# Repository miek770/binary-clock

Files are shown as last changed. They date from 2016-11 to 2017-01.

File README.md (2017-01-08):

# Binary Clock

This is a simple binary clock project using a PIC18F2220, pretty much for:

1. The fun of it;
2. Getting more experience with Eagle PCB design;
3. Doing a first PIC C project (I've only programmed PICs in assembly before).

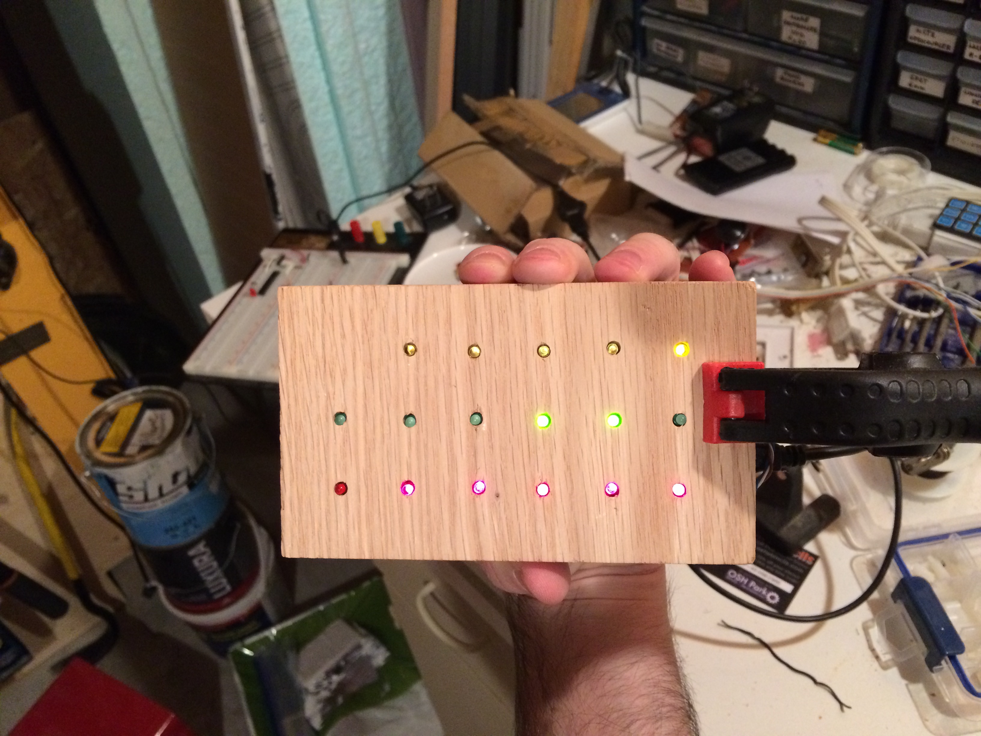
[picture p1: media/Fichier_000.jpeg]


The clamp on the right is there to hold down the buttons (hidden) while the glue dries up. More pictures in [media](https://github.com/miek770/binary-clock/tree/master/media)!

## To Do List

- Adjust timing to account for the cycles it takes for the time update and LED syncing. I noted an about 10 minutes drift over 24 hours, but I didn't take precise measurements at the beginning of the cycle. I just took another picture with my PC clock showing the seconds and the binary clock, and will compare the difference in at least 24 hours. I could also double-check by calculating the amount of cycles required for the interrupt subroutine;
    - Edit: This explaination is wrong; the timer doesn't stop counting while the ISR executes. I think the problem may be that I skip a "beat" because the ISR sometimes lasts longer than TMR0's 256 cycles counter. I'll see if the drift matches this assumption after a day.
- Test the low charge detection;
- Consider using delays.h instead of timer1 for the low-battery blink. The use of the timer seems unecessary and it would be a good excuse to explore the available functions;
- Consider importing timers.h to setup timer0, instead of manually setting each register;
- Consider using the idle power management mode when nothing is happening to reduce battery consumption. First check if it would interfere with timer0;

## Appearance

### Display

The clock uses 5 LEDs (bits) for the hours (24h format), 6 for the minutes and 6 for the seconds. Showing fractions of seconds seemed excessive.

## Supply

It can be fed either or by both:

1. 3x AA batteries;
2. A micro-USB port.

### Low Charge Detection

Both supplies are paralleled with diodes, and the PIC monitors the batteries' voltage so that an alarm (blinking LED) is raised when the batteries are low. For 1.5V AA batteries, this would be pretty much when they get under 1V. AN0 is used on the PIC to measure the battery voltage.

Hum thinking about it makes me realize that the voltage reference is Vdd. So if we ignore the voltage drop through the diode, which is gonna be constant, the voltage drop at the battery (with no USB supply) is going to drop proportionally with Vdd which means the AN0 measurement won't pick it up. Unless I use the voltage drop across the diode as a reference. At 4.5V at the batteries, with a 0.7V drop through the diode I'll get 3.8V at Vdd. When the batteries get to 3V (1V per cell), Vdd will equal 2.3V.

So Vbatt/Vdd = 4.5V/3.8V (1.184) at full charge, and 3V/2.3V (1.304) at low charge. Using a 50/50 voltage divider between Vbatt and AN0, the ratios would be 0.592 (full) and 0.652 (low). With a 10-bit A/D converter I have a 1024 resolution, which would be able to measure this. Basically the reading is going to go from 0/1023 to 1023/1023. A 0.592 ratio (full) would be read as 606 and a 0.652 ratio (low) as 667. So I could then consider any reading over 666 (0b1010011010) as a low battery charge.

This will need to be adjusted to account for the real diode voltage drop as well as the voltage divider ratio, but it should do the trick. For testing purposes I could use the time diodes to show the A/D conversion output. I have up to 17 bits (5+6+6 diodes).

## Timing

I switched from the PIC18F252 to the PIC18F2220 because the former doesn't have an internal oscillator. I assumed it did.

I will be using TMR0 to count seconds, using a bresenham algorithm as explained and implemented here: [http://www.romanblack.com/one_sec.htm](http://www.romanblack.com/one_sec.htm)

Basically (this is all from his website above):

    This next one is similar to the 1 second generators above. However it is optimised for speed and code space, because it uses a 16bit unsigned int variable for bres instead of a 32bit unsigned long. We do this by using values for the int period and the 1second period that are in the same ratio to each other, but smaller! We divide both values by 16;

    Optimised C code for a 1 second period with a 1MHz timer (4MHz xtal);

        // uses 1 variable; unsigned int bres
        // gets here every TMR0 int (every 256 ticks)

        bres += 16; // add (256/16) ticks to bresenham total

        if(bres >= 62500)   // if reached (1000000/16) 1 second!
        {
            bres -= 62500;  // subtract 1 second, retain error
            do_1sec_event();    // update clock, etc
        }

This is neat!

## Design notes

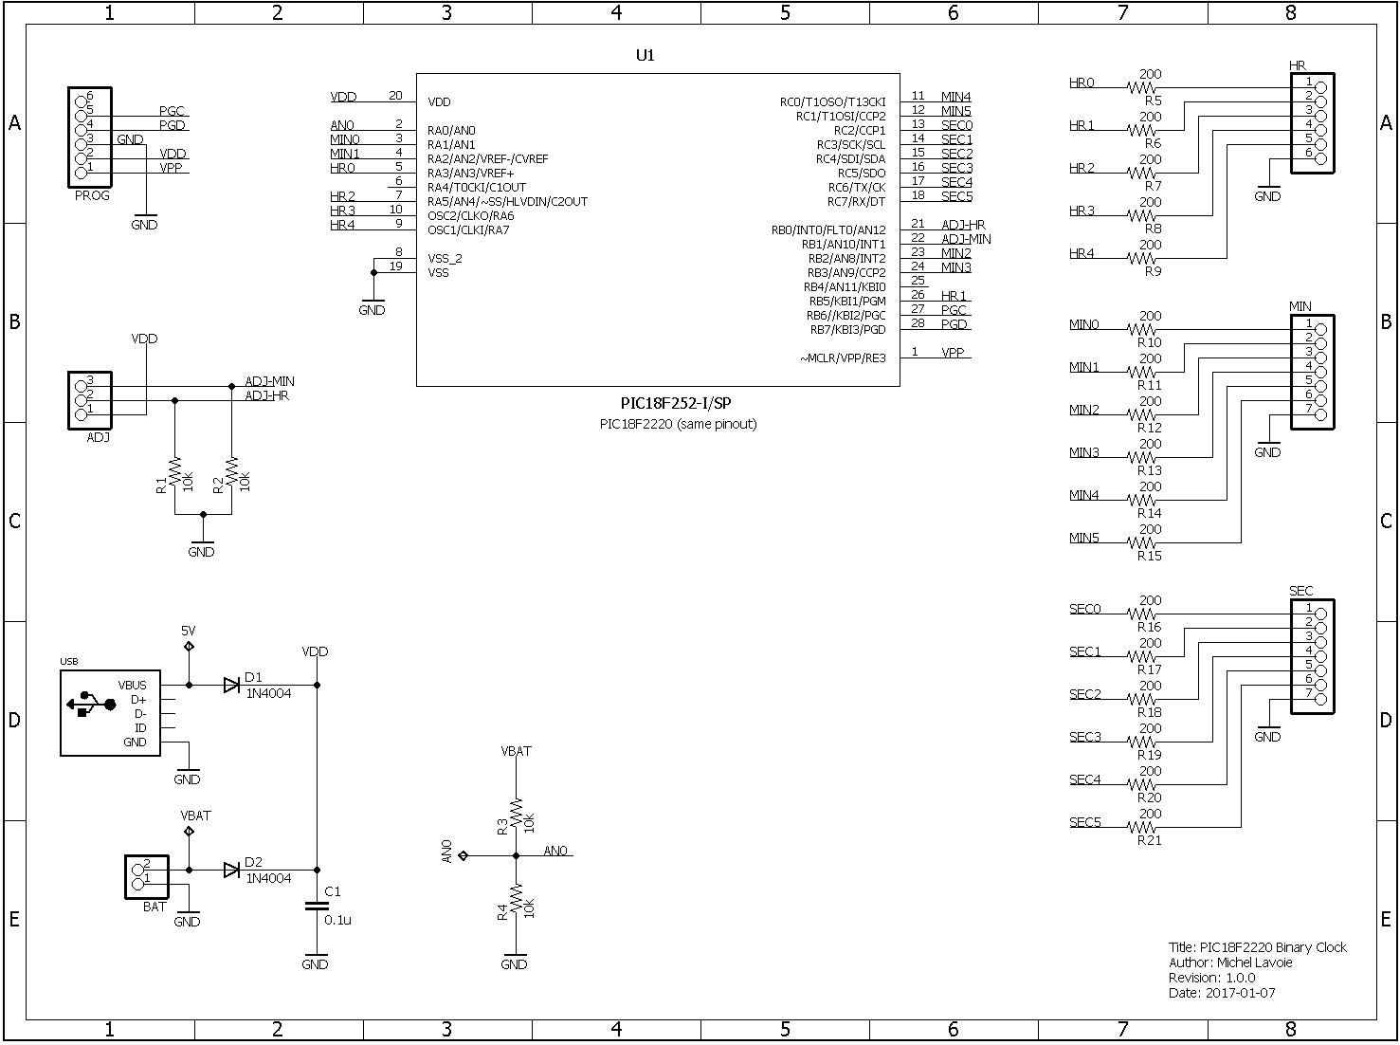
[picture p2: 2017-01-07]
media/Schematic.png

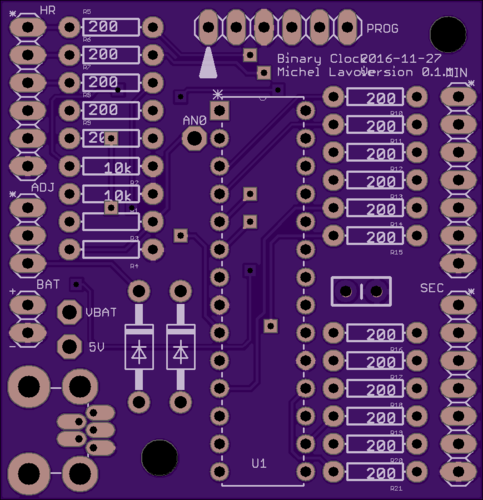
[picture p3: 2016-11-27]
media/Board Top.png

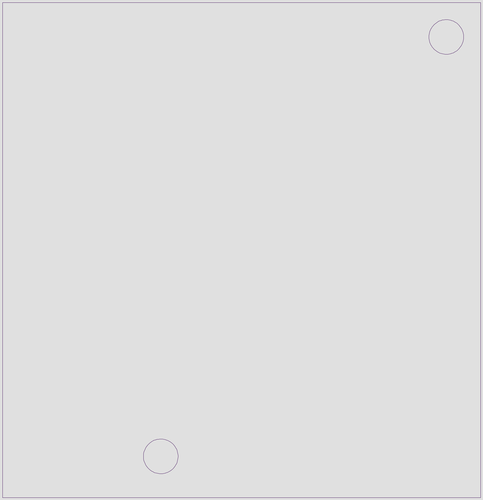
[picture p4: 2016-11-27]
media/Board Outline.png

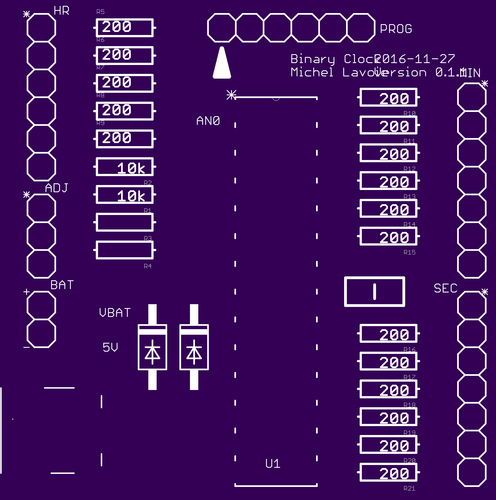
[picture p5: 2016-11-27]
media/Top Silk Screen.png

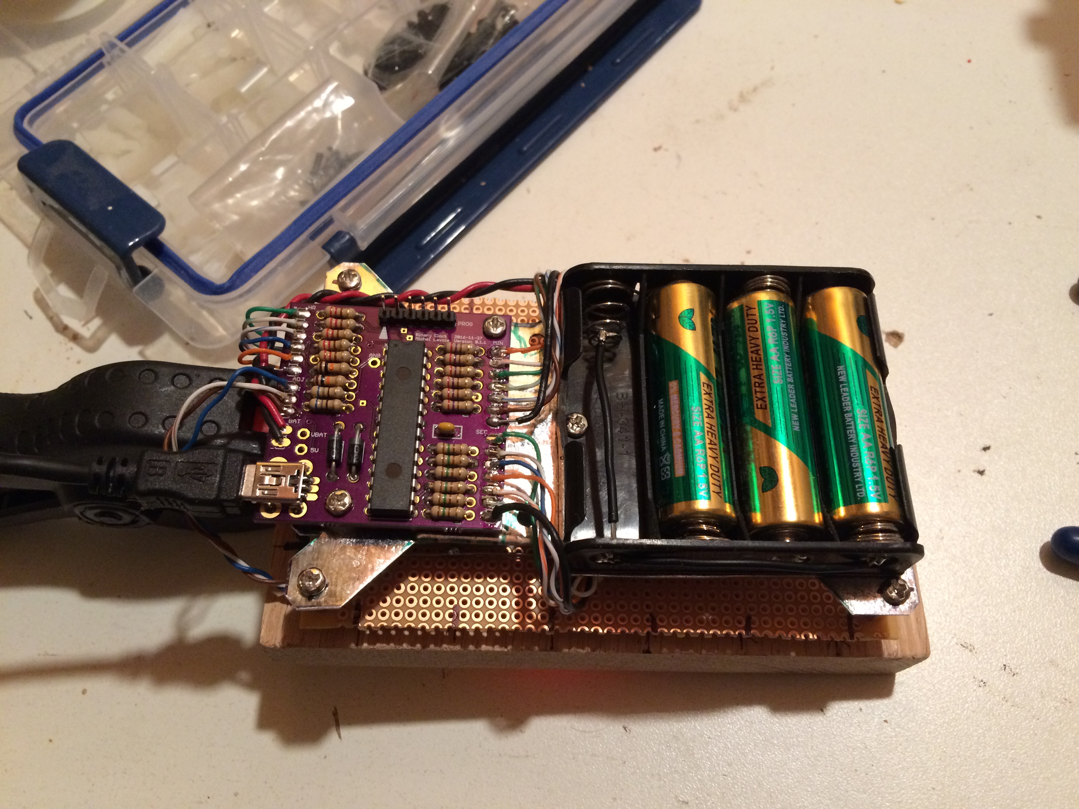
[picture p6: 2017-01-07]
media/Fichier_001.jpeg

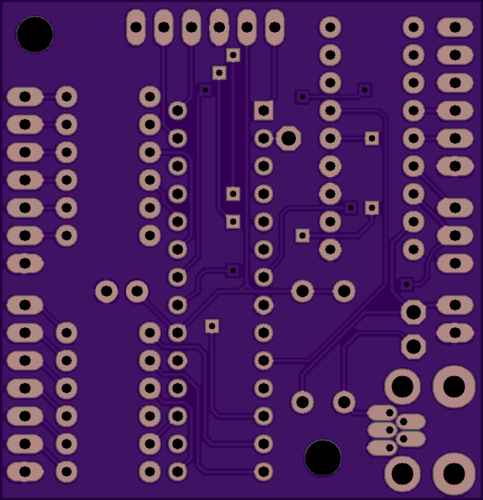
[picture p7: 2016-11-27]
media/Board Bottom.png

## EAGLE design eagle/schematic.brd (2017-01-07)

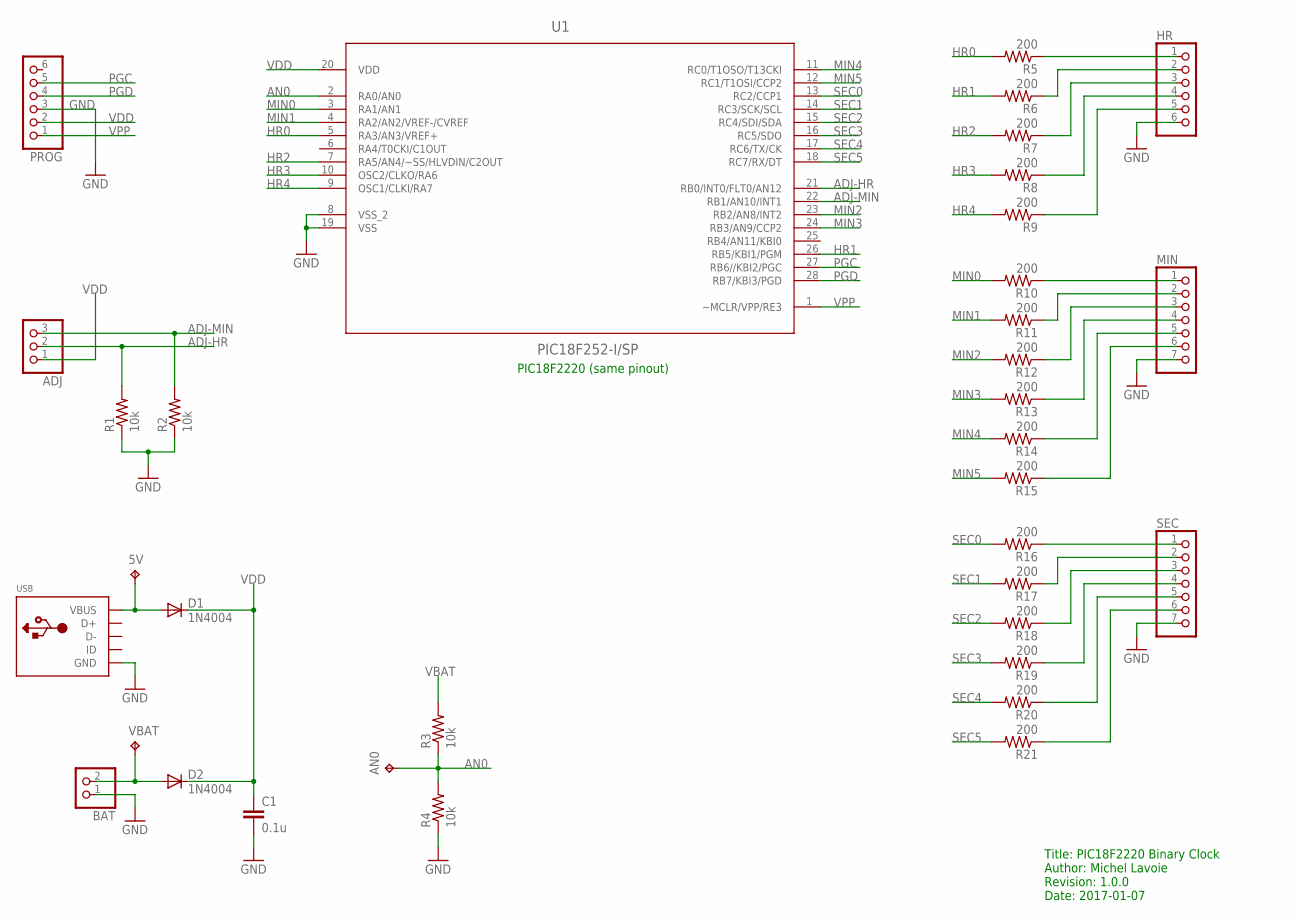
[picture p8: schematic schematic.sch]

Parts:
5V: TPPAD1-13; P1-13
ADJ: PINHD-1X3; 1X03
AN0: TPPAD1-13; P1-13
BAT: PINHD-1X2; 1X02
C1: 0.1u; CAP-PTH-SMALL-KIT
D1, D2: 1N4004; DO41-10
HR: PINHD-1X6; 1X06
MIN: PINHD-1X7; 1X07
PROG: PINHD-1X6; 1X06
R1, R2, R3, R4: 10k; AXIAL-0.3
R5, R6, R7, R8, R9, R10, R11, R12, R13, R14, R15, R16, R17, R18, R19, R20, R21: 200; AXIAL-0.3
SEC: PINHD-1X7; 1X07
U1: PIC18F252-I/SP; DIP254P762X508-28
USB: USBTHM; USB-MINIB-THM
VBAT: TPPAD1-13; P1-13

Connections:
5V: 5V.TP, D1.A, USB.VBUS
ADJ-HR: ADJ.2, R1.P$2 (2), U1.21 (RB0/INT0/FLT0/AN12)
ADJ-MIN: ADJ.3, R2.P$2 (2), U1.22 (RB1/AN10/INT1)
AN0: AN0.TP, R3.P$1 (1), R4.P$2 (2), U1.2 (RA0/AN0)
GND: BAT.1, C1.2, HR.6, MIN.7, PROG.3, R1.P$1 (1), R2.P$1 (1), R4.P$1 (1), SEC.7, U1.8 (VSS_2), U1.19 (VSS), USB.GND
HR0: R5.P$2 (2), U1.5 (RA3/AN3/VREF+)
HR1: R6.P$2 (2), U1.26 (RB5/KBI1/PGM)
HR2: R7.P$2 (2), U1.7 (RA5/AN4/~SS/HLVDIN/C2OUT)
HR3: R8.P$2 (2), U1.10 (OSC2/CLKO/RA6)
HR4: R9.P$2 (2), U1.9 (OSC1/CLKI/RA7)
MIN0: R10.P$2 (2), U1.3 (RA1/AN1)
MIN1: R11.P$2 (2), U1.4 (RA2/AN2/VREF-/CVREF)
MIN2: R12.P$2 (2), U1.23 (RB2/AN8/INT2)
MIN3: R13.P$2 (2), U1.24 (RB3/AN9/CCP2)
MIN4: R14.P$2 (2), U1.11 (RC0/T1OSO/T13CKI)
MIN5: R15.P$2 (2), U1.12 (RC1/T1OSI/CCP2)
unnamed: HR.1, R5.P$1 (1)
unnamed: HR.2, R6.P$1 (1)
unnamed: HR.3, R7.P$1 (1)
unnamed: HR.4, R8.P$1 (1)
unnamed: HR.5, R9.P$1 (1)
unnamed: MIN.1, R10.P$1 (1)
unnamed: MIN.2, R11.P$1 (1)
unnamed: MIN.3, R12.P$1 (1)
unnamed: MIN.4, R13.P$1 (1)
unnamed: MIN.5, R14.P$1 (1)
unnamed: MIN.6, R15.P$1 (1)
unnamed: R16.P$1 (1), SEC.1
unnamed: R17.P$1 (1), SEC.2
unnamed: R18.P$1 (1), SEC.3
unnamed: R19.P$1 (1), SEC.4
unnamed: R20.P$1 (1), SEC.5
unnamed: R21.P$1 (1), SEC.6
PGC: PROG.5, U1.27 (RB6//KBI2/PGC)
PGD: PROG.4, U1.28 (RB7/KBI3/PGD)
SEC0: R16.P$2 (2), U1.13 (RC2/CCP1)
SEC1: R17.P$2 (2), U1.14 (RC3/SCK/SCL)
SEC2: R18.P$2 (2), U1.15 (RC4/SDI/SDA)
SEC3: R19.P$2 (2), U1.16 (RC5/SDO)
SEC4: R20.P$2 (2), U1.17 (RC6/TX/CK)
SEC5: R21.P$2 (2), U1.18 (RC7/RX/DT)
VBAT: BAT.2, D2.A, R3.P$2 (2), VBAT.TP
VDD: ADJ.1, C1.1, D1.C, D2.C, PROG.2, U1.20 (VDD)
VPP: PROG.1, U1.1 (~MCLR/VPP/RE3)

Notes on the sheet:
Title: PIC18F2220 Binary Clock Author: Michel Lavoie Revision: 1.0.0 Date: 2017-01-07
PIC18F2220 (same pinout)

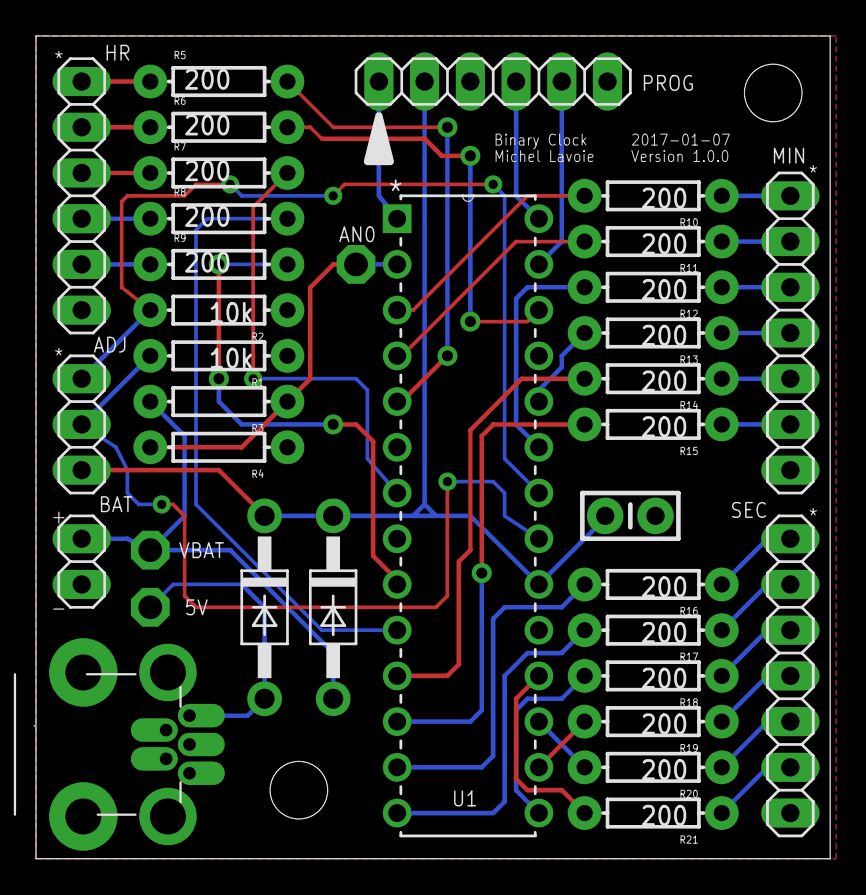
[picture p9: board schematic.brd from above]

Board: 2 copper layers, 44.1 x 45.7 mm, 35 parts (0 on the bottom side), 44 nets.

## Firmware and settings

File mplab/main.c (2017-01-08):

#include <p18f2220.h>

// Configuration
#pragma config OSC = INTIO2
#pragma config WDT = OFF
#pragma config BOR = OFF
#pragma config PWRT = OFF
#pragma config LVP = OFF
#pragma config MCLRE = OFF

// Prototypes - Functions
void update_time(void);
void refresh_clock(void);
void blink(void);
void sync_leds(void);
void isr(void);

// Prototypes - Configurations
void conf_tmr0(void);
void conf_adc(void);
void conf_int(void);
void conf_osc(void);
void conf_tmr1(void);
void conf_ports(void);
unsigned char get_bit(unsigned char byte, unsigned char pos);

/* Initialized variables declarations

Using "access" and "near" ensures that the data be saved in the accessram
region of the data memory (quicker access).

Using "volatile" is recommended by the C18 User's Guide when the variable
is to be used by the ISR as well as other functions. Basically it ensures
that the variable isn't cached during execution so changes in either the
normal program or interrupt routines are reflected in each other. */

#pragma idata access accessram
volatile near unsigned int bres = 0;
volatile near unsigned char hour = 0b11;
volatile near unsigned char min = 0b11;
volatile near unsigned char sec = 0b11;

// High-priority interrupt vector
#pragma code high_vector = 0x08
void interrupt_at_high_vector(void) {
	_asm GOTO isr _endasm
}

#pragma code

// Interrupt subroutine (priorities are disabled)

#pragma interrupt isr
void isr (void) {
	
	// See www.romanblack.com/one_sec.htm for details
	// Values below work for 4MHz clock (Fosc/4 = 1MHz)
	if (INTCONbits.TMR0IF) {
		bres += 16; // add (256/16) ticks to bresenham total
		//LATCbits.LATC7 ^= 1; // For testing

		if (bres >= 62500) { // if reached (1000000/16) 1 second!
			bres -= 62500; // subtract 1 second, retain error
			sec += 1;
			update_time();
			sync_leds();
			ADCON0bits.GO = 1; // Check battery level
		}

		INTCONbits.TMR0IF = 0; // Reset flag
	}

	// A/D conversion is complete
	else if (PIR1bits.ADIF) {
		// Check if battery voltage under 1V/cell
		if (ADRESH >= 0b10 && ADRESL >= 0b10011010) {
			blink(); // Initiates RA7 blink
		}
		PIR1bits.ADIF = 0; // Reset flag
	}

	// Time to blink!
	else if (PIR1bits.TMR1IF) {
		LATAbits.LATA7 ^= 1; // Toggle RA7
		T1CONbits.TMR1ON = 0; // Turn off TMR1
		PIR1bits.TMR1IF = 0; // Reset flag
	}

	// Hour adjustment!
	else if (INTCONbits.INT0IF) {
		hour += 1;
		update_time();
		sync_leds();
		INTCONbits.INT0IF = 0; // Reset flag
	}

	// Min adjustment!
	else if (INTCON3bits.INT1IF) {
		min += 1;
		update_time();
		sync_leds();
		INTCON3bits.INT1IF = 0; // Reset flag
	}
}

// Main code
#pragma code
void main (void) {
	conf_osc(); // Oscillator configuration
	conf_int(); // Interrupts configuration
	conf_tmr0(); // Timer0 - To count seconds
	conf_tmr1(); // Timer1 - To blink RA7 (low battery)
	conf_adc(); // A/D converter
	conf_ports(); // Ports A,B,C

	sync_leds();

	while (1); // Loop indefinitely
}

// Other functions
unsigned char get_bit(unsigned char byte, unsigned char pos) {
	return (byte >> pos) & 1;
}

void blink(void) {
	LATAbits.LATA7 ^= 1; // Toggle RA7
	T1CONbits.TMR1ON = 1; // Turn on TMR1
}

void update_time(void) {
	if (sec == 60) {
		sec = 0;
		min += 1;
		if (min == 60) {
			min = 0;
			hour += 1;
			if (hour == 24) {
				hour = 0;
			}
		}
	}
}

void sync_leds(void) {
	LATAbits.LATA3 = get_bit(hour, 0);
	LATBbits.LATB5 = get_bit(hour, 1);
	LATAbits.LATA5 = get_bit(hour, 2);
	LATAbits.LATA6 = get_bit(hour, 3);
	LATAbits.LATA7 = get_bit(hour, 4);

	LATAbits.LATA1 = get_bit(min, 0);
	LATAbits.LATA2 = get_bit(min, 1);
	LATBbits.LATB2 = get_bit(min, 2);
	LATBbits.LATB3 = get_bit(min, 3);
	LATCbits.LATC0 = get_bit(min, 4);
	LATCbits.LATC1 = get_bit(min, 5);

	LATCbits.LATC2 = get_bit(sec, 0);
	LATCbits.LATC3 = get_bit(sec, 1);
	LATCbits.LATC4 = get_bit(sec, 2);
	LATCbits.LATC5 = get_bit(sec, 3);
	LATCbits.LATC6 = get_bit(sec, 4);
	LATCbits.LATC7 = get_bit(sec, 5);
}

// Configurations
void conf_ports(void) {
	TRISA = 0b00010001;
	LATA = 0x00;
	TRISB = 0b11010011;
	LATB = 0x00;
	TRISC = 0b00000000;
	LATC = 0x00;
}

void conf_osc(void) {
	OSCCONbits.IDLEN = 1; // Idle mode enabled; CPU core is not clocked in power managed modes
	OSCCONbits.IRCF2 = 1; // 4 MHz
	OSCCONbits.IRCF1 = 1;
	OSCCONbits.IRCF0 = 0;
	OSCCONbits.SCS1 = 1; // Internal oscillator block (RC modes)
}

void conf_int(void) {
	RCONbits.IPEN = 0; // Disable interrupt priority
	INTCONbits.GIE = 1; // Enable all interrupt sources
	INTCONbits.PEIE = 1; // Enable peripheral interrupt sources
	INTCONbits.TMR0IE = 1; // Enable TMR0 interrupt
	INTCONbits.INT0IE = 1; // Enable INT0 interrupt
	INTCON2bits.INTEDG0 = 1; // INT0 on rising edge
	INTCON3bits.INT1IE = 0; // Enable INT1 interrupt
	INTCON2bits.INTEDG1 = 1; // INT1 on rising edge
	PIE1bits.ADIE = 1; // Enable A/D conversion interrupt
}

void conf_tmr0(void) {
	T0CONbits.TMR0ON = 1; // Enable TMR0
	T0CONbits.T08BIT = 1; // 8-bit timer (256 ticks)
	T0CONbits.T0CS = 0; // Internal instruction cycle clock
	T0CONbits.PSA = 1; // Bypass prescaler
}

void conf_tmr1(void) {
	T1CONbits.T1CKPS1 = 0; // 1:2 prescale value
	T1CONbits.T1CKPS0 = 1;
	T1CONbits.TMR1CS = 0; // Internal clock (Fosc/4)
	T1CONbits.TMR1ON = 0; // Disable TMR1
}

void conf_adc(void) {
	ADCON0bits.CHS3 = 0; // AN0 (battery voltage)
	ADCON0bits.CHS2 = 0;
	ADCON0bits.CHS1 = 0;
	ADCON0bits.CHS0 = 0;
	ADCON0bits.ADON = 1; // A/D converter module is enabled
	ADCON1bits.VCFG1 = 0; // VREFL = AVss
	ADCON1bits.VCFG0 = 0; // VREFH = AVdd
	ADCON1bits.PCFG3 = 1; // AN0 = analog, others = digital
	ADCON1bits.PCFG2 = 1;
	ADCON1bits.PCFG1 = 1;
	ADCON1bits.PCFG0 = 0;
	ADCON2bits.ADFM = 1; // A/D result right justified (don't know the point..)
	ADCON2bits.ACQT2 = 1; // 20 Tad (acquisition time)
	ADCON2bits.ACQT1 = 1;
	ADCON2bits.ACQT0 = 1;
	ADCON2bits.ADCS2 = 0; // Fosc/8
	ADCON2bits.ADCS1 = 0;
	ADCON2bits.ADCS0 = 1;
}

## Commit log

2016-11-26 New schematic
    [schematic.sch]
2016-11-27 PCB in progress
    [schematic.brd, schematic.sch]
2016-11-27 PCB completed
    [schematic.brd, schematic.sch]
2016-11-27 Interrupts for adjustments
2016-11-27 Version 0.1.1. Applied all items in the To Do list.
    [schematic.brd, schematic.sch]
2016-11-27 Adjusted title font size. Order sent to OSH Park.
    [schematic.brd]
2016-11-29 Changed PIC18F252 for PIC18F2220, the former has no internal oscillator.
    [main.c]
2016-11-30 Configuration and timing interrupt in progress... duty calls.
2016-12-01 A/D configuration and basic interrupt.
2016-12-01 Method for voltage measurement.
2016-12-02 Seem to have finished the code, but can't test it without the PCB (or a test circuit).
2016-12-02 Noted to switch from 4 to 3 AA batteries.
2016-12-02 Added time adjustment interrupts.
2016-12-04 Removed 'near' qualifier, it raised error 1303. Not sure why.
    [main.c]
2016-12-04 Fixed the issue with 'near' qualifier.
    [main.c]
2016-12-04 Replaced PORT with LAT for digital outputs.
    [main.c]
2017-01-06 further debugging for RA4 (pin 6, hour bit 1)
2017-01-07 Corrigé les bugs restants, mis à jour la documentation
    [schematic.brd, schematic.sch]
2017-01-08 Added further notes regarding time drift, as well as new theory
    [main.c]
2017-01-10 Calculated time shift
    [Time shift.ods]

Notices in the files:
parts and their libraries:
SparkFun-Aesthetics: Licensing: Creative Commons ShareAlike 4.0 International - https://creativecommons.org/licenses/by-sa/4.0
